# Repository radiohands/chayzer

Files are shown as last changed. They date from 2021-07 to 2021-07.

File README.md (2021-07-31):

# chayzer
Go in to the individual directories for more information

### Chayzer Chording keyboard

Board that I designed to be used with the https://artsey.io chording layout. Of course this can be modified to work in other ways "macro pad" etc.

When using an OLED screen on the pcb, make sure the pin's match, there are some versions that you can buy that have the wrong pin locations for this board

If you use the latter, you will have to somehow twist the pins around without having them touch... (not easy and can dammage it)
```
Supposed to be (looking from the top):
GND VCC SCL SDA

NOT:
VCC GND SCL SDA
```
---
chayzer
---
chayzer

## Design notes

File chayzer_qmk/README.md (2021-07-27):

# artsey

artsey.io implementation for the Chayzer keyboard.

How to set up the code:
* Install QMK for your system and test run making a .hex file for a board.
-- https://beta.docs.qmk.fm/tutorial/newbs_getting_started
* Get the source and move it to where your current QMK setup is. (you might not have to do this if your install is up to date)
```
git clone https://github.com/qmk/qmk_firmware
```
* Merge with combo (from the qmk_firmware root directory for your installation)
```
git remote add sevanteri_early_combo https://github.com/sevanteri/qmk_firmware.git
git fetch sevanteri_early_combo
git checkout -b mod-tap-combos sevanteri_early_combo/early_combo
git pull sevanteri_early_combo early_combo
```

* Make submodules (lufa error)
```
make git-submodule
```
* Copy all of the files from https://github.com/artseyio/artsey-qmk/tree/main/left_hand (except for the keymaps directory and files inside) to the chayzer directory (not to the chayzer/keymaps directory)
* The final directory will look like:
```
├── keymaps
|   ├── artsey_left
|       ├── keymap.c     [chayzer original file]
|       ├── oled.c       [chayzer original]
├── artsey.c             [artsey original file ]
├── artsey.h             [artsey original]
├── artsey_basic.def     [artsey]
├── artsey_combos.csv    [artsey]
├── artsey_keycodes.csv  [artsey]
├── chayzer.c            [chayzer]
├── chayzer.h            [chayzer]
├── combos.def           [artsey]
├── config.h             [chayzer]
├── generator.R          [artsey]
├── info.json            [chayzer]
├── keymap_combo.h       [artsey]
├── macros.c             [artsey]
├── readme.md            [chayzer]
├── rules.mk             [chayzer]
```
* Copy the chayzer keyboard directory to qmk_firmware/keyboards
* Make the keyboard
```
make chayzer:artsey_left
```

chayzer

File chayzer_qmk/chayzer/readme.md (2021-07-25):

# chayzer

chayzer

*A short description of the keyboard/project*

* Keyboard Maintainer: [radiohands](https://github.com/yourusername)
* Hardware Supported: *The PCBs, controllers supported*
* Hardware Availability: *Links to where you can find this hardware*

Make example for this keyboard (after setting up your build environment):

    make chayzer:default

Flashing example for this keyboard:

    make chayzer:default:flash

See the [build environment setup](https://docs.qmk.fm/#/getting_started_build_tools) and the [make instructions](https://docs.qmk.fm/#/getting_started_make_guide) for more information. Brand new to QMK? Start with our [Complete Newbs Guide](https://docs.qmk.fm/#/newbs).

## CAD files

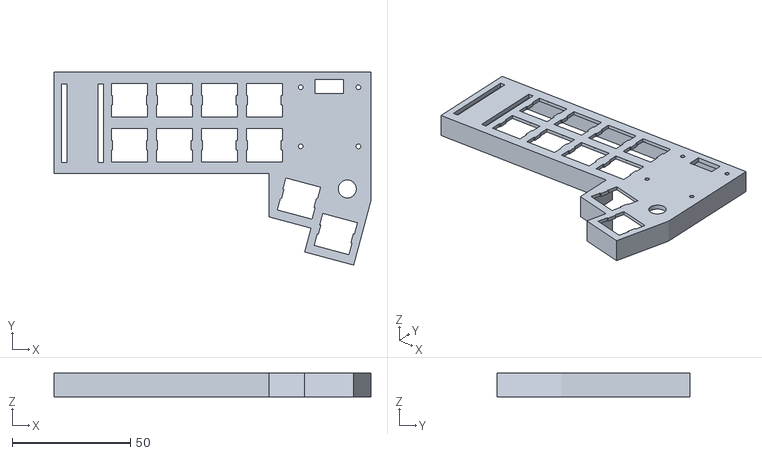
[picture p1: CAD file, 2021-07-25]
3d_print_original_proto/chayzer.stl
134.0 x 81.6 x 10.0

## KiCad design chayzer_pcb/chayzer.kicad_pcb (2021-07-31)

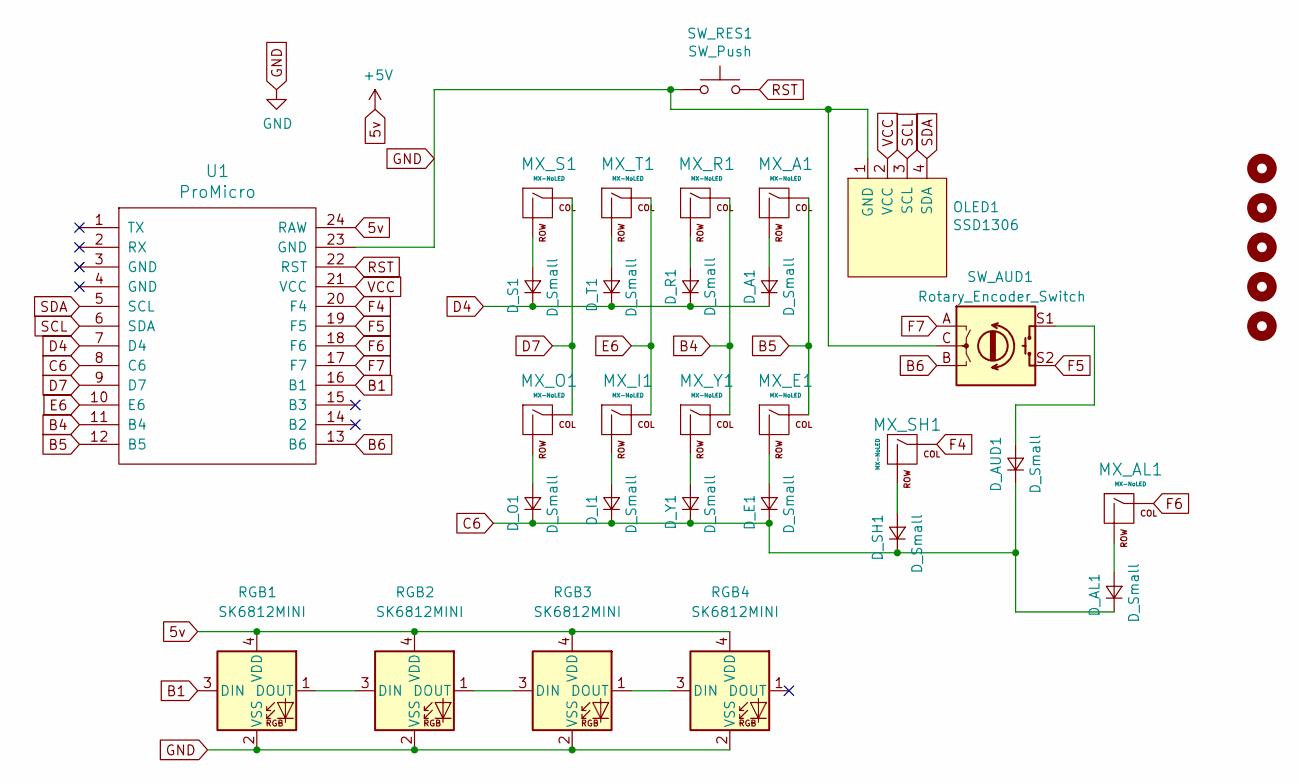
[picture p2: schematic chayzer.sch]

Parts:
D_A1: D_Small; D_DO-35_SOD27_P7.62mm_Horizontal
D_AL1: D_Small; D_DO-35_SOD27_P7.62mm_Horizontal
D_AUD1: D_Small; D_DO-35_SOD27_P7.62mm_Horizontal
D_E1: D_Small; D_DO-35_SOD27_P7.62mm_Horizontal
D_I1: D_Small; D_DO-35_SOD27_P7.62mm_Horizontal
D_O1: D_Small; D_DO-35_SOD27_P7.62mm_Horizontal
D_R1: D_Small; D_DO-35_SOD27_P7.62mm_Horizontal
D_S1: D_Small; D_DO-35_SOD27_P7.62mm_Horizontal
D_SH1: D_Small; D_DO-35_SOD27_P7.62mm_Horizontal
D_T1: D_Small; D_DO-35_SOD27_P7.62mm_Horizontal
D_Y1: D_Small; D_DO-35_SOD27_P7.62mm_Horizontal
H1, H2, H3, H4, H5: MountingHole; MountingHole_3.2mm_M3
MX_A1: MX-NoLED; Kailh_socket_MX_optional
MX_AL1: MX-NoLED; Kailh_socket_MX_optional
MX_E1: MX-NoLED; Kailh_socket_MX_optional
MX_I1: MX-NoLED; Kailh_socket_MX_optional
MX_O1: MX-NoLED; Kailh_socket_MX_optional
MX_R1: MX-NoLED; Kailh_socket_MX_optional
MX_S1: MX-NoLED; Kailh_socket_MX_optional
MX_SH1: MX-NoLED; Kailh_socket_MX_optional
MX_T1: MX-NoLED; Kailh_socket_MX_optional
MX_Y1: MX-NoLED; Kailh_socket_MX_optional
OLED1: SSD1306; 128x64OLED
RGB1, RGB2, RGB3, RGB4: SK6812MINI; LED_SK6812MINI_PLCC4_3.5x3.5mm_P1.75mm
SW_AUD1: Rotary_Encoder_Switch; RotaryEncoder_Alps_EC12E-Switch_Vertical_H20mm
SW_RES1: SW_Push; SW_PUSH_6mm_H4.3mm
U1: ProMicro

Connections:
5v: RGB1.4 (VDD), RGB2.4 (VDD), RGB3.4 (VDD), RGB4.4 (VDD), U1.24 (RAW)
B1: RGB1.3 (DIN), U1.16 (B1)
B4: MX_R1.1 (COL), MX_Y1.1 (COL), U1.11 (B4)
B5: MX_A1.1 (COL), MX_E1.1 (COL), U1.12 (B5)
B6: SW_AUD1.B, U1.13 (B6)
C6: D_AL1.1 (K), D_AUD1.1 (K), D_E1.1 (K), D_I1.1 (K), D_O1.1 (K), D_SH1.1 (K), D_Y1.1 (K), U1.8 (C6)
D4: D_A1.1 (K), D_R1.1 (K), D_S1.1 (K), D_T1.1 (K), U1.7 (D4)
D7: MX_O1.1 (COL), MX_S1.1 (COL), U1.9 (D7)
E6: MX_I1.1 (COL), MX_T1.1 (COL), U1.10 (E6)
F4: MX_SH1.1 (COL), U1.20 (F4)
F5: SW_AUD1.S2, U1.19 (F5)
F6: MX_AL1.1 (COL), U1.18 (F6)
F7: SW_AUD1.A, U1.17 (F7)
GND: OLED1.1 (GND), RGB1.2 (VSS), RGB2.2 (VSS), RGB3.2 (VSS), RGB4.2 (VSS), SW_AUD1.C, SW_RES1.1, U1.23 (GND)
unnamed: D_A1.2 (A), MX_A1.2 (ROW)
unnamed: D_AL1.2 (A), MX_AL1.2 (ROW)
unnamed: D_AUD1.2 (A), SW_AUD1.S1
unnamed: D_E1.2 (A), MX_E1.2 (ROW)
unnamed: D_I1.2 (A), MX_I1.2 (ROW)
unnamed: D_O1.2 (A), MX_O1.2 (ROW)
unnamed: D_R1.2 (A), MX_R1.2 (ROW)
unnamed: D_S1.2 (A), MX_S1.2 (ROW)
unnamed: D_SH1.2 (A), MX_SH1.2 (ROW)
unnamed: D_T1.2 (A), MX_T1.2 (ROW)
unnamed: D_Y1.2 (A), MX_Y1.2 (ROW)
unnamed: RGB1.1 (DOUT), RGB2.3 (DIN)
unnamed: RGB2.1 (DOUT), RGB3.3 (DIN)
unnamed: RGB3.1 (DOUT), RGB4.3 (DIN)
RST: SW_RES1.2, U1.22 (RST)
SCL: OLED1.3 (SCL), U1.6 (SDA)
SDA: OLED1.4 (SDA), U1.5 (SCL)
VCC: OLED1.2 (VCC), U1.21 (VCC)

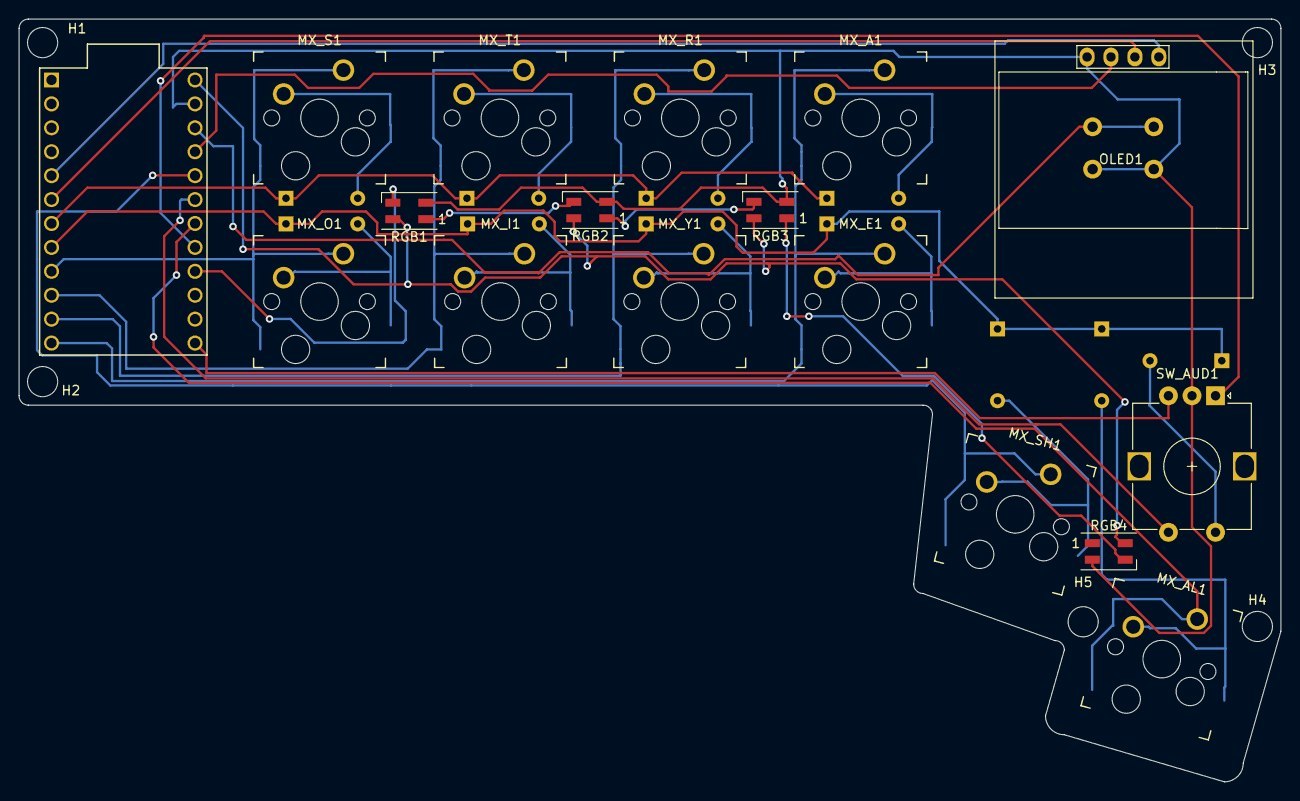
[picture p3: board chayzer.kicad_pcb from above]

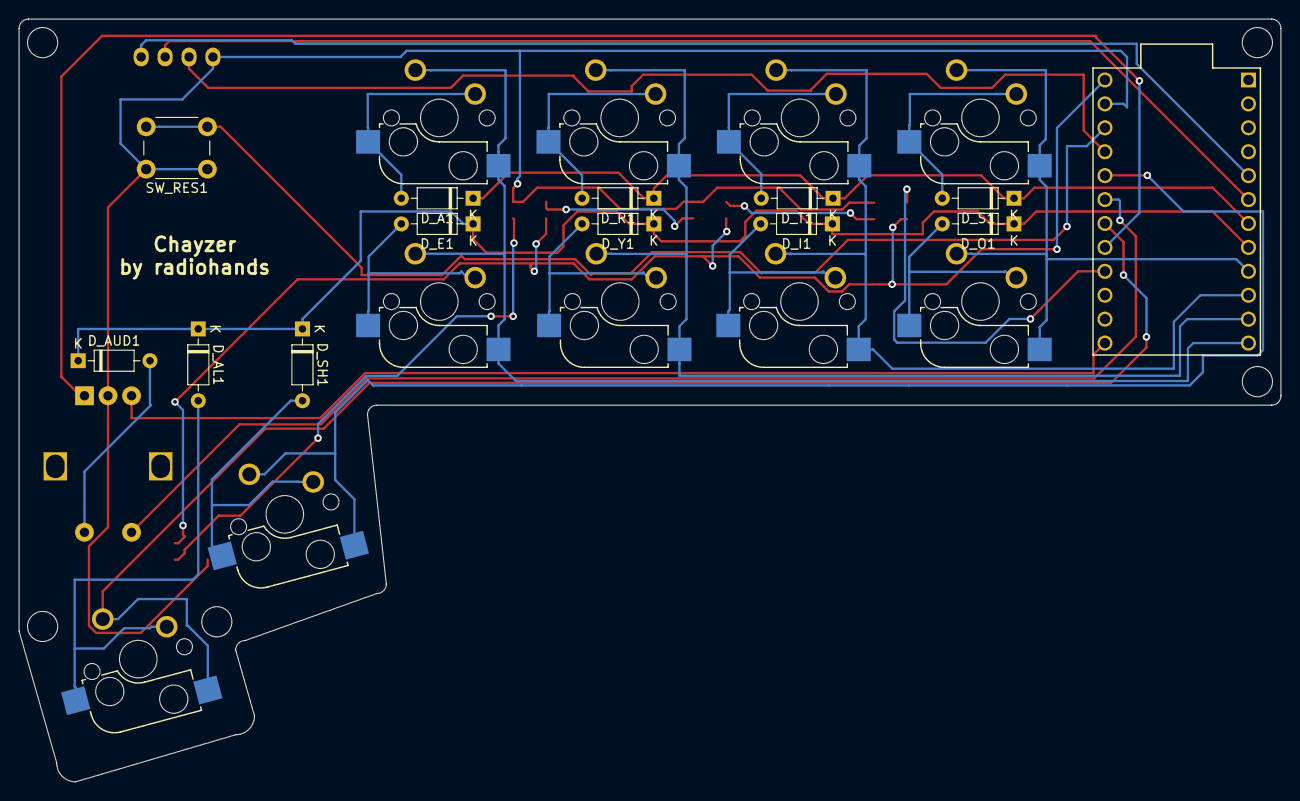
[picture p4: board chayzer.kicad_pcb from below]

Board: 2 copper layers, 134.0 x 81.0 mm, 34 parts (12 on the bottom side), 32 nets.

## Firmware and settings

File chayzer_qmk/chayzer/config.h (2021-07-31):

/*
Copyright 2021 radiohands

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
You should have received a copy of the GNU General Public License
along with this program.  If not, see <http://www.gnu.org/licenses/>.
*/

#pragma once

#include "config_common.h"

/* USB Device descriptor parameter */
#define VENDOR_ID    0xFEED
#define PRODUCT_ID   0x0000
#define DEVICE_VER   0x0001
#define MANUFACTURER radiohands
#define PRODUCT      chayzer

/* key matrix size */
#define MATRIX_ROWS 2
#define MATRIX_COLS 7

/*
 * Keyboard Matrix Assignments
 *
 * Change this to how you wired your keyboard
 * COLS: AVR pins used for columns, left to right
 * ROWS: AVR pins used for rows, top to bottom
 * DIODE_DIRECTION: COL2ROW = COL = Anode (+), ROW = Cathode (-, marked on diode)
 *                  ROW2COL = ROW = Anode (+), COL = Cathode (-, marked on diode)
 *
 */
#define MATRIX_ROW_PINS { D4, C6 }
#define MATRIX_COL_PINS { D7, E6, B4, B5, F4, F5, F6 }
#define UNUSED_PINS

// Encoder

#define ENCODERS_PAD_A { F7 }
#define ENCODERS_PAD_B { B6 }

/* COL2ROW, ROW2COL */
#define DIODE_DIRECTION COL2ROW

/* Debounce reduces chatter (unintended double-presses) - set 0 if debouncing is not needed */
#define DEBOUNCE 5

/* Mechanical locking support. Use KC_LCAP, KC_LNUM or KC_LSCR instead in keymap */
#define LOCKING_SUPPORT_ENABLE
/* Locking resynchronize hack */
#define LOCKING_RESYNC_ENABLE

/* disable these deprecated features by default */
#define NO_ACTION_MACRO
#define NO_ACTION_FUNCTION
#define OLED_DISPLAY_128X64


// RGB stuff, disabled until I can figure out why it's bugging out
//#define RGB_DI_PIN B1
//#define RGBLED_NUM 4
//#define RGBLIGHT_HUE_STEP 5
//#define RGBLIGHT_EFFECT_RAINBOW_SWIRL
//#define RGBLIGHT_EFFECT_KNIGHT
//#define RGBLIGHT_SNAKE
//#define RGBLIGHT_TWINKLE

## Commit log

2021-07-25 initial file upload
    [artsey_combos.csv, artsey_keycodes.csv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]
2021-07-27 cleared up the readme a little
    [artsey_combos.csv, artsey_keycodes.csv]
2021-07-27 moved the encoder up a bit
    [chayzer-B_Cu.gbr, chayzer-B_Mask.gbr, chayzer-B_SilkS.gbr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]
2021-07-27 cleaned up schematic
2021-07-31 added rgb to PCB, buggy in qmk right now, and untested on PCB
    [chayzer-B_Cu.gbr, chayzer-B_Mask.gbr, chayzer-B_SilkS.gbr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]

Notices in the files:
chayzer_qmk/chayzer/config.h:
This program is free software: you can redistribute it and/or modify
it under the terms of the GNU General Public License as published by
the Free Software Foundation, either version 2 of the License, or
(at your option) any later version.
